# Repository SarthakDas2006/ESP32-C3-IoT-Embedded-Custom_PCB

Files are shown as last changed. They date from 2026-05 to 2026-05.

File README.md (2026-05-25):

# ESP32-C3-IoT-Embedded-Custom_PCB
4-layer ESP32-C3 based custom embedded IoT PCB featuring onboard temperature & humidity, light, and audio sensing, USB Type-C, Li-Po charging, and external flash memory. Designed for smart embedded systems, wireless IoT applications, portable sensing, automation, and edge device prototyping.
A professionally designed 4-layer ESP32-based IoT development board created using KiCad.
This project was developed to explore real-world PCB engineering concepts including multilayer routing, power management, USB-C integration, sensor interfacing, and signal integrity practices.

# 📸 Project Preview

## 3D PCB Render


# 🚀 Features

- ESP32-C3-WROOM module with onboard antenna
- 4-layer PCB stackup
- USB Type-C interface
- Li-Ion battery charging circuit
- Onboard voltage regulation
- SD card interface
- External SPI flash memory
- Temperature and humidity sensor interface
- Photo sensor interface
- Microphone and amplifier circuitry
- Reset and Boot buttons
- Ground plane optimization
- Decoupling and filtering capacitors
- Test points for debugging

# 🧠 PCB Stackup

| Layer | Function |
|---|---|
| Top Layer | Signal Routing |
| Inner Layer 1 | Ground Plane |
| Inner Layer 2 | Power Plane |
| Bottom Layer | Signal Routing |

The multilayer architecture was designed to improve:
- signal integrity
- grounding
- EMI performance
- power distribution

# 🛠️ Tools Used

- KiCad
- NextPCB DFM tool (HQDFM)
- SnapEDA
- ESP32-C3 Ecosystem
- Multiple datasheets

# 🔌 Hardware Blocks

## ESP32-C3 Module
Main microcontroller responsible for:
- WiFi/Bluetooth communication
- sensor interfacing
- data processing
- IoT applications

## USB Type-C Interface
Used for:
- power input
- USB communication
- firmware flashing

Includes:
- filtering capacitors
- protection circuitry
- proper VBUS routing

## Li-Ion Charging Circuit
Portable power management section featuring:
- battery charging
- regulated power delivery
- charging indication circuitry

## SD Card Interface
SPI-based SD card module used for:
- data logging
- external storage
- sensor data recording

## Sensor Interfaces
The PCB includes provisions for:
- temperature and humidity sensing
- ambient light sensing
- audio input through microphone amplifier circuitry

# 📂 Repository Structure

```text
ESP32-C3-IoT-Embedded-Custom-PCB/
│
├── BOM files/
├── Datasheets/
├── Drill files/
├── Gerber files/
├── Images/
├── custom 3d model libraries/
├── custom footprint libraries/
├── custom symbol libraries/
│
├── ESP32_IoT_4-layer_PCB.kicad_pcb
├── ESP32_IoT_4-layer_PCB.kicad_pro
├── ESP32_IoT_4-layer_PCB.kicad_sch
│
└── README.md
```

# 🎯 Project Objectives

This project was built to gain practical experience in:

- multilayer PCB design
- signal routing
- power integrity
- USB-C hardware implementation
- grounding techniques
- schematic hierarchy
- PCB manufacturing workflow

# 🧪 Key Design Considerations

- Ground plane continuity
- Proper decoupling capacitor placement
- Power filtering and stabilization
- Analog and digital section separation
- Pull-up and pull-down resistor implementation
- Modular schematic organization

# 📦 Manufacturing Ready

The project includes:
- PCB layout
- schematic
- Gerber files
- drill files
- BOM support

Compatible with manufacturers such as:
- JLCPCB
- PCBWay
- NextPCB

# 🔮 Future Improvements

- OTA firmware updates
- CAN bus support
- additional onboard sensors
- low-power optimization
- enclosure design
- impedance-controlled routing

# 📚 Learning Outcomes

Through this project, I developed understanding of:

- multilayer PCB stackups
- copper pours and ground planes
- signal routing
- ESP32 hardware integration
- USB-C implementation
- PCB manufacturing workflow
- hardware debugging concepts

# 👨‍💻 Author

**Sarthak Das**  
Electrical and Electronics Engineering Student at VIT Chennai

# ⭐ Support

If you like this project:
- Star the repository
- Fork the project
- Share feedback and suggestions

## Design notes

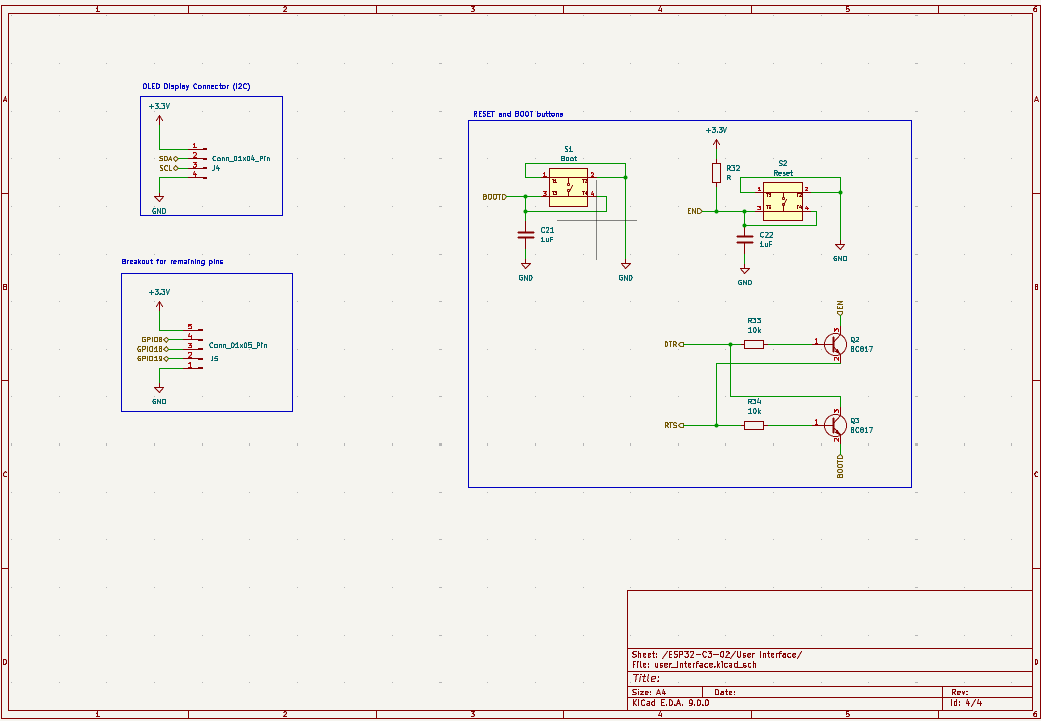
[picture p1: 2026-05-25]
Images/Schematic_editor_sheet_4.png

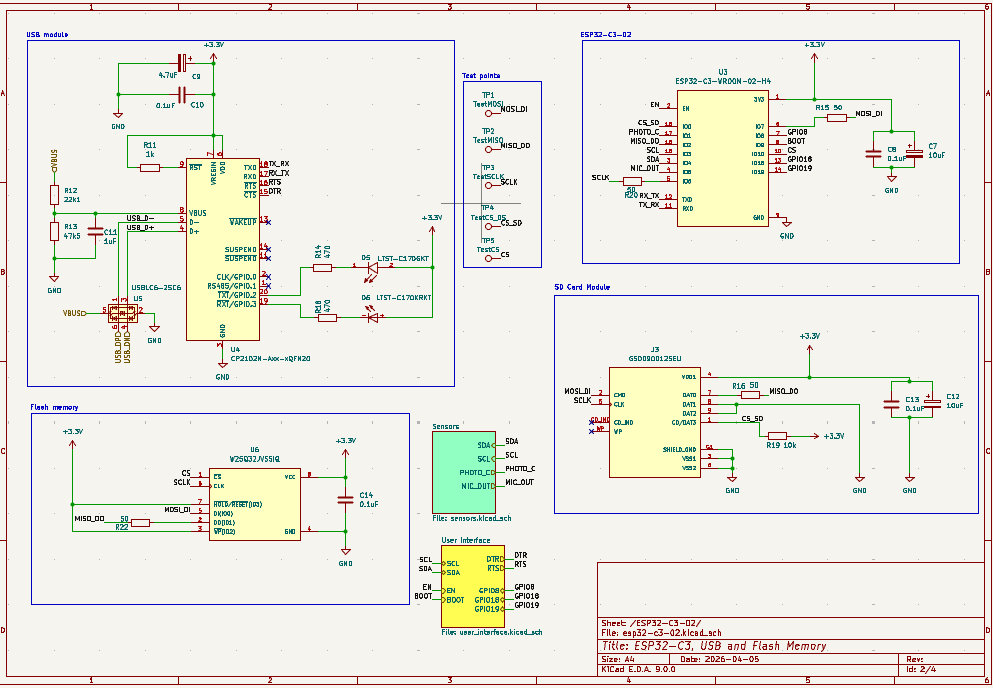
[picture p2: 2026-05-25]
Images/Schematic_editor_sheet_2.png

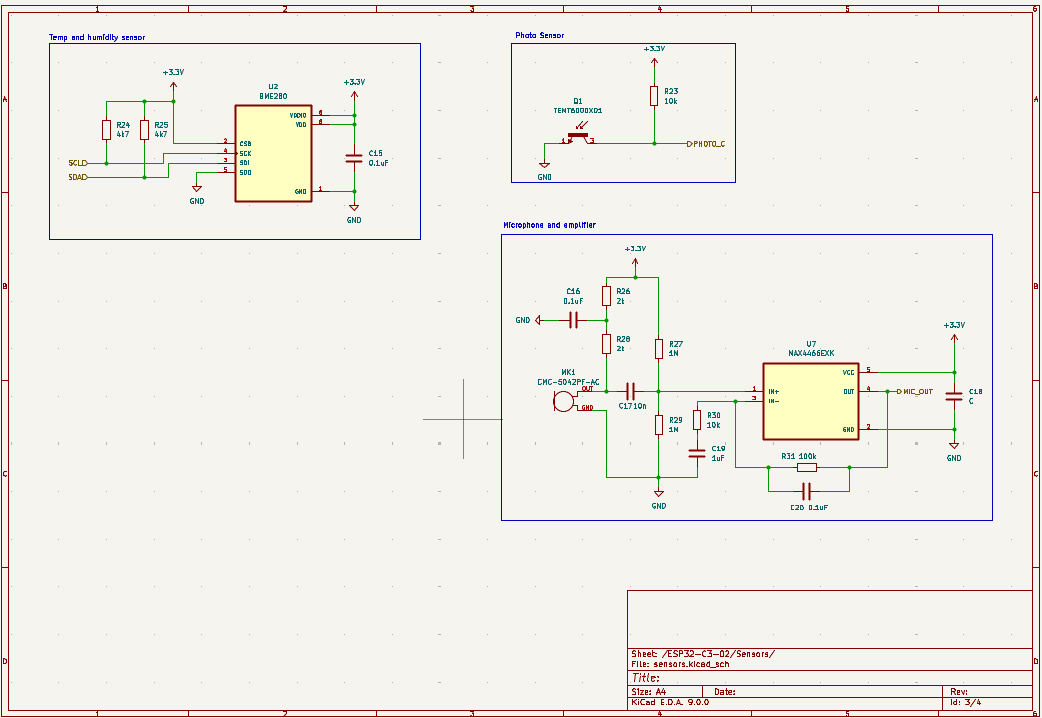
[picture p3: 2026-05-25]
Images/Schematic_editor_sheet_3.png

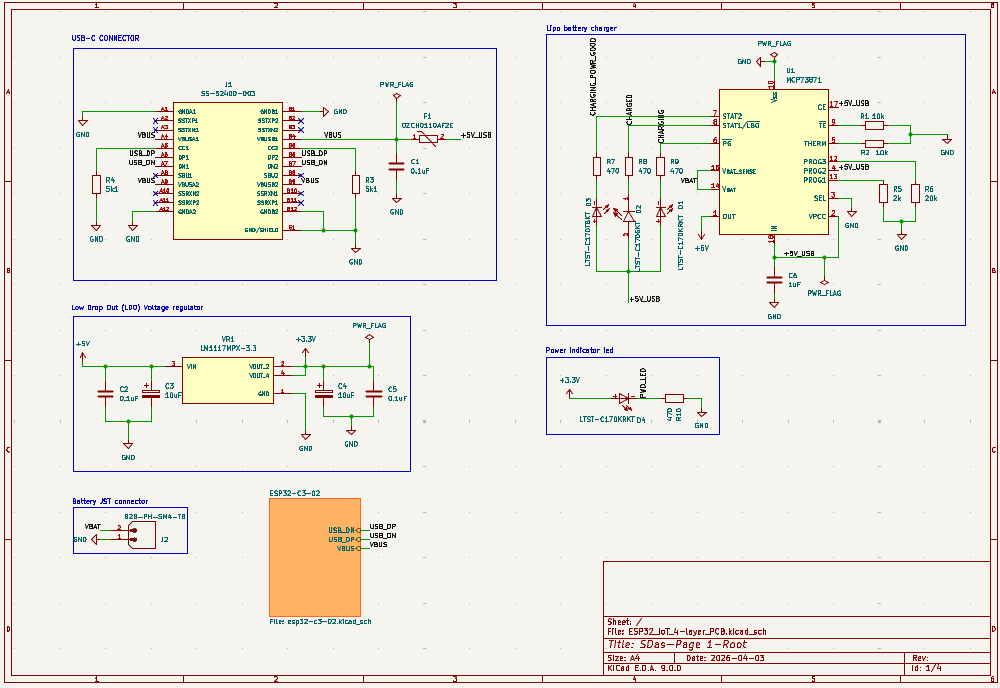
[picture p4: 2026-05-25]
Images/Schematic_editor_sheet_1.png

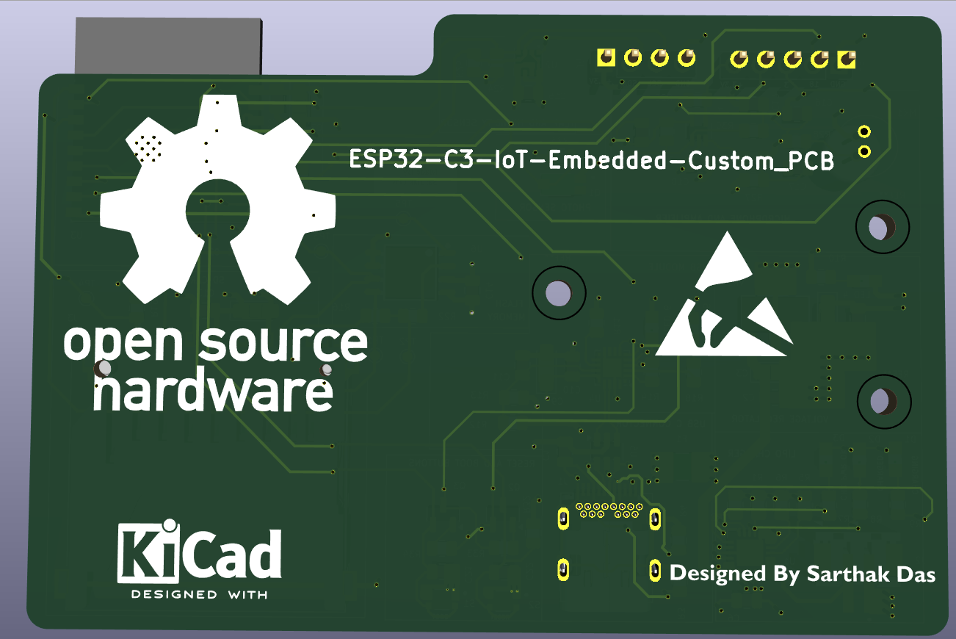
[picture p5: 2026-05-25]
Images/3d_model_bottom_view.png

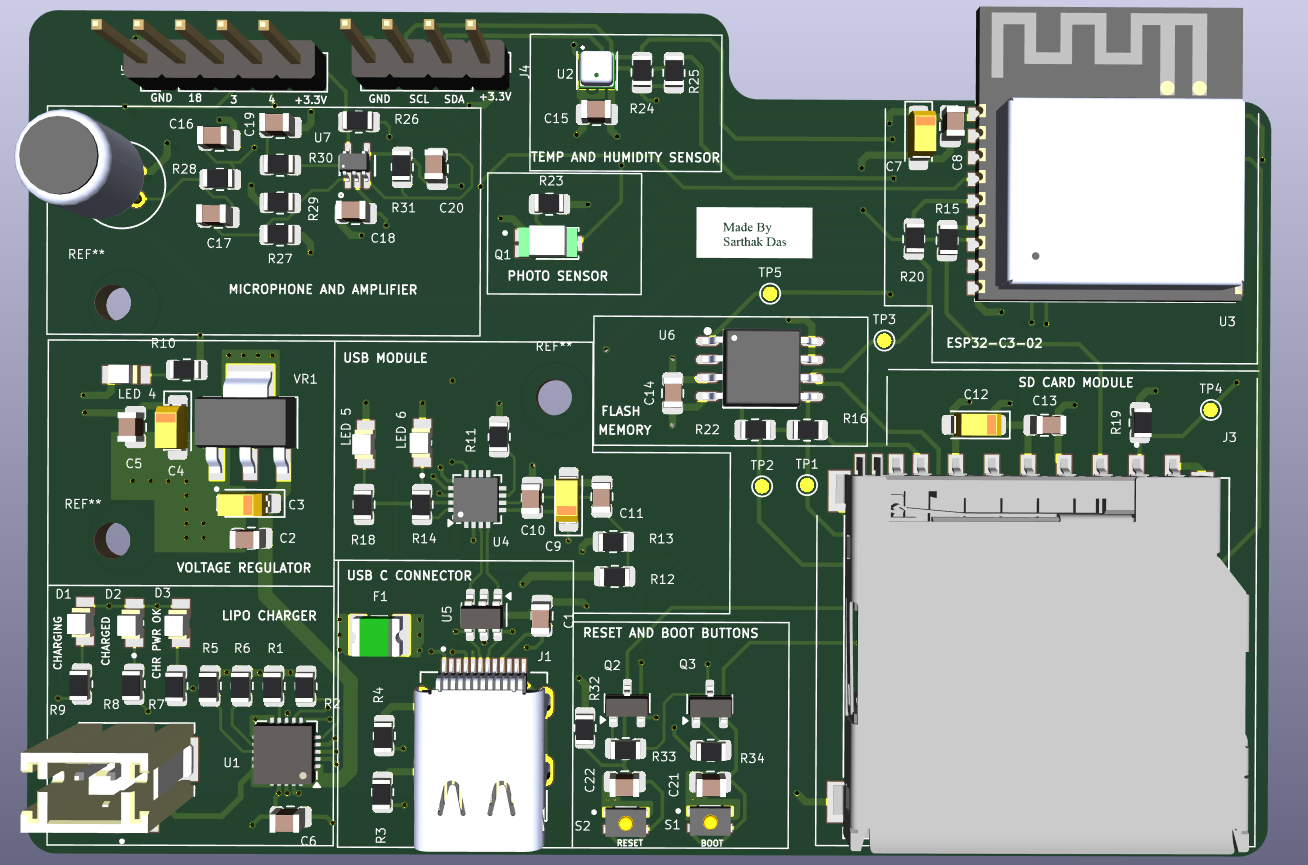
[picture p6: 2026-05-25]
Images/3d_model_top_view.png

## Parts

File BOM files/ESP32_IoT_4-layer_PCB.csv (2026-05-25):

Id | Designator | Footprint | Quantity | Designation | Supplier and ref
1 | R4,R3 | R_0805_2012Metric | 2 | 5k1
2 | R25,R24 | R_0805_2012Metric | 2 | 4k7
3 | R14,R18,R8,R10,R7,R9 | R_0805_2012Metric | 6 | 470
4 | C19,C11,C6,C22,C21 | C_0805_2012Metric | 5 | 1uF
5 | R29,R27 | R_0805_2012Metric | 2 | 1M
6 | MK1 | CUI_CMC-5042PF-AC | 1 | CMC-5042PF-AC
7 | J3 | AMPHENOL_GSD090012SEU | 1 | GSD090012SEU
8 | TP4 | TestPoint_Pad_D1.0mm | 1 | TestCS_DS
9 | D3 | DIOC200X125X110 | 1 | LTST-C170TBKT
10 | S2 | SW_USLPT2819DT2TR | 1 | Reset
11 | R26,R28,R5 | R_0805_2012Metric | 3 | 2k
12 | U2 | PSON65P250X250X100-8N | 1 | BME280
13 | U3 | MODULE_ESP32-C3-WROOM-02-H4 | 1 | ESP32-C3-WROOM-02-H4
14 | TP3 | TestPoint_Pad_D1.0mm | 1 | TestSCLK
15 | C1,C15,C5,C14,C16,C13,C2,C10,C8,C20 | C_0805_2012Metric | 10 | 0.1uF
16 | VR1 | VREG_LM1117MPX-3.3 | 1 | LM1117MPX-3.3
17 | U4 | SiliconLabs_QFN-20-1EP_3x3mm_P0.5mm_EP1.8x1.8mm | 1 | CP2102N-Axx-xQFN20
18 | Q2,Q3 | SOT-23 | 2 | BC817
19 | R11 | R_0805_2012Metric | 1 | 1k
20 | R32 | R_0805_2012Metric | 1 | R
21 | U1 | QFN-20-1EP_4x4mm_P0.5mm_EP2.5x2.5mm | 1 | MCP73871
22 | R15,R22,R16,R20 | R_0805_2012Metric | 4 | 50
23 | R19,R1,R2,R30,R34,R33,R23 | R_0805_2012Metric | 7 | 10k
24 | C4,C7,C3,C12 | CP_EIA-3216-18_Kemet-A_Pad1.58x1.35mm_HandSolder | 4 | 10uF
25 | LED 5,LED 4,D1 | DIOC200X125X110R | 3 | LTST-C170KRKT
26 | R31 | R_0805_2012Metric | 1 | 100k
27 | C9 | CP_EIA-3216-18_Kemet-A_Pad1.58x1.35mm_HandSolder | 1 | 4.7uF
28 | J2 | JST_B2B-PH-SM4-TB | 1 | B2B-PH-SM4-TB
29 | J5 | PinHeader_1x05_P2.54mm_Vertical | 1 | Conn_01x05_Pin
30 | J1 | BELFUSE_SS-52400-003 | 1 | SS-52400-003
31 | F1 | FUSC3225X100N | 1 | 0ZCH0110AF2E
32 | R12 | R_0805_2012Metric | 1 | 22k1
33 | U6 | SOIC127P790X216-8N | 1 | W25Q32JVSSIQ
34 | TP5 | TestPoint_Pad_D1.0mm | 1 | TestCS
35 | LED 6,D2 | LED_LTST-C170GKT | 2 | LTST-C170GKT
36 | U5 | SOT-23-6 | 1 | USBLC6-2SC6
37 | C17 | C_0805_2012Metric | 1 | 10n
38 | U7 | SOT65P210X110-5N | 1 | MAX4466EXK
39 | J4 | PinHeader_1x04_P2.54mm_Vertical | 1 | Conn_01x04_Pin
40 | C18 | C_0805_2012Metric | 1 | C
41 | S1 | SW_USLPT2819DT2TR | 1 | Boot
42 | TP1 | TestPoint_Pad_D1.0mm | 1 | TestMOSI
43 | R13 | R_0805_2012Metric | 1 | 47k5
44 | R6 | R_0805_2012Metric | 1 | 20k
45 | Q1 | TRANS_TEMT6000X01 | 1 | TEMT6000X01
46 | TP2 | TestPoint_Pad_D1.0mm | 1 | TestMISO

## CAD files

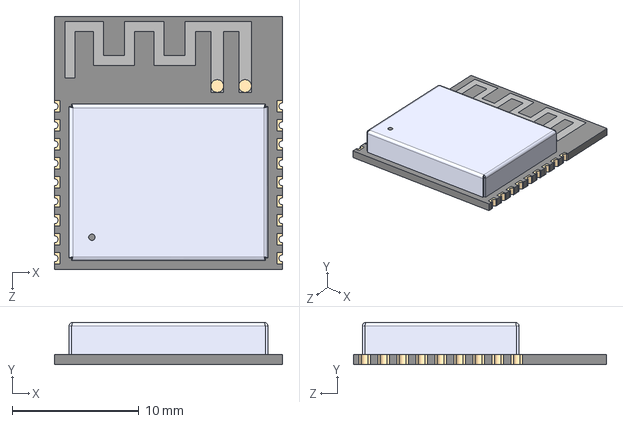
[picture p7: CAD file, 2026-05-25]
custom 3d model libraries/ESP32-C3-WROOM-02-H4.step
18.0 x 3.35 x 20.0 mm

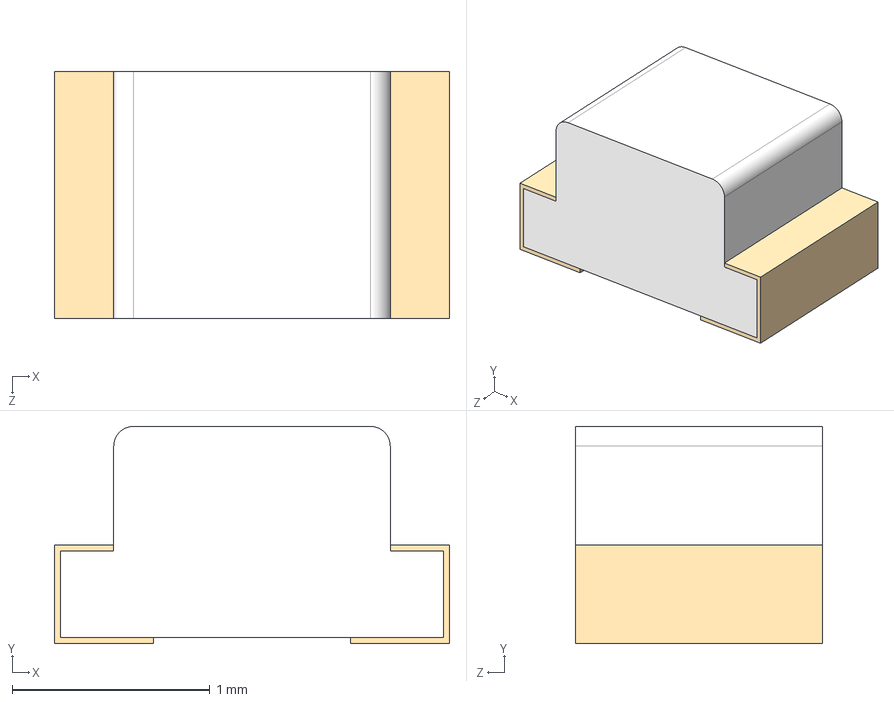
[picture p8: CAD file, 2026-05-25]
custom 3d model libraries/LTST-C170TBKT.step
2.00 x 1.10 x 1.25 mm

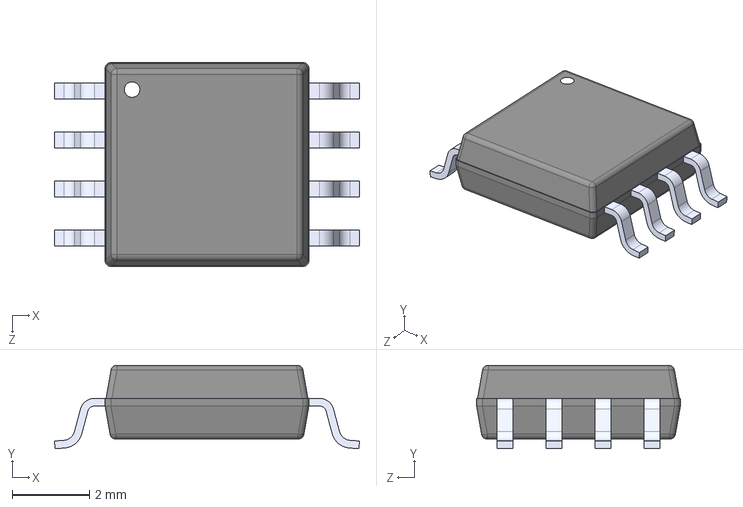
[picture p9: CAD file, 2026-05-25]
custom 3d model libraries/W25Q32JVSSIQ.step
7.90 x 2.16 x 5.28 mm

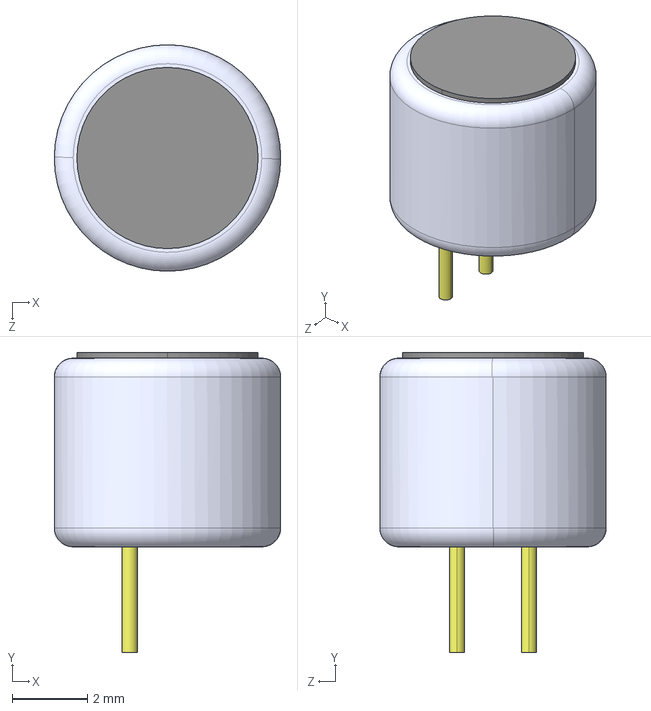
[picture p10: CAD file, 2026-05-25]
custom 3d model libraries/CMC-5042PF-AC.step
6.00 x 7.95 x 6.00 mm

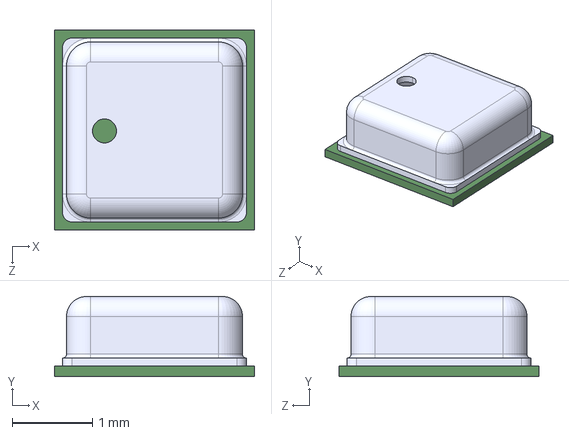
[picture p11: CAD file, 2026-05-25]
custom 3d model libraries/BME280.step
2.50 x 1.00 x 2.50 mm

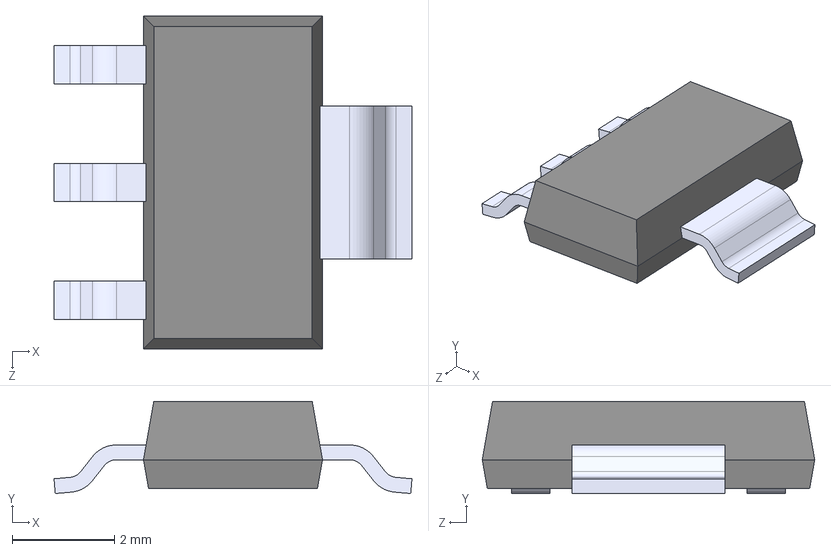
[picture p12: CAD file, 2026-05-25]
custom 3d model libraries/LM1117MPX-3.3.step
7.00 x 1.80 x 6.50 mm

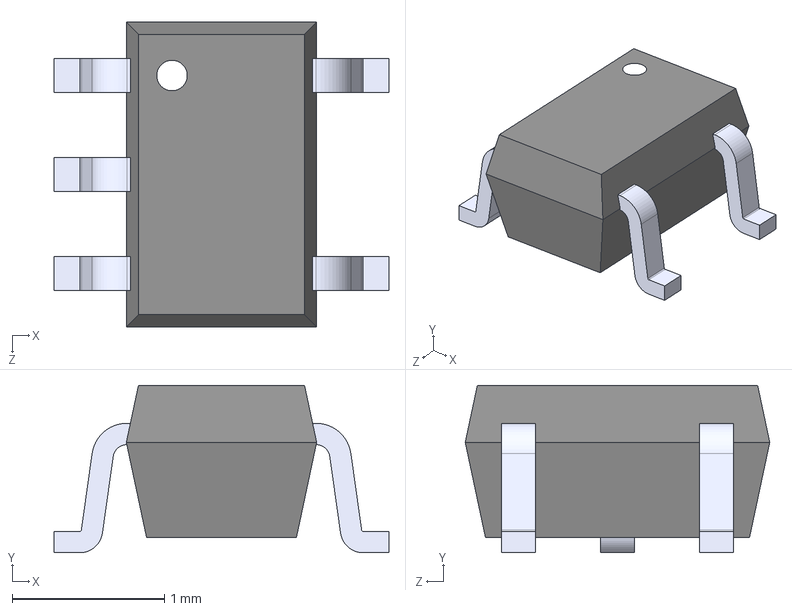
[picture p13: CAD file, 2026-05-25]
custom 3d model libraries/MAX4466EXK.step
2.20 x 1.10 x 2.00 mm

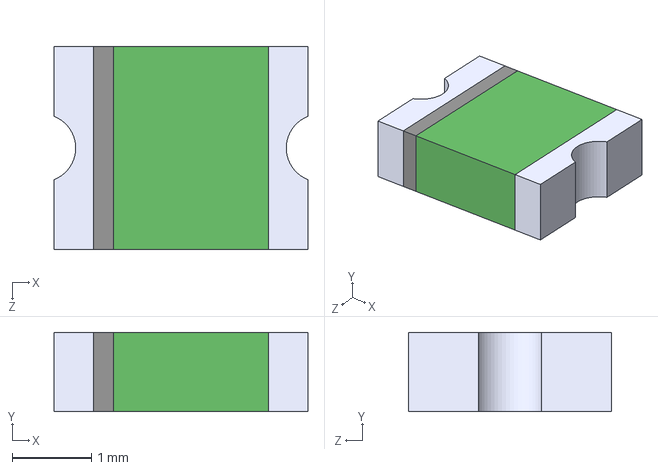
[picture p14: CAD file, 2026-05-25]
custom 3d model libraries/0ZCH0110AF2E.step
3.21 x 1.00 x 2.58 mm

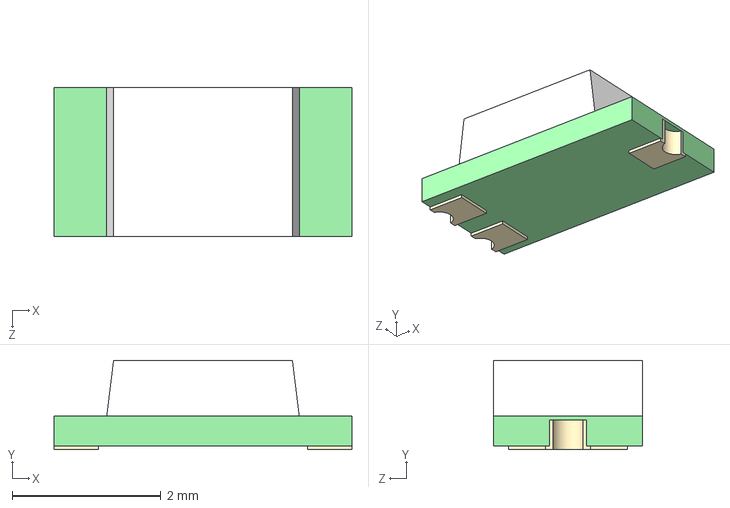
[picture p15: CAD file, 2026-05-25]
custom 3d model libraries/TEMT6000X01.step
4.00 x 1.20 x 2.00 mm

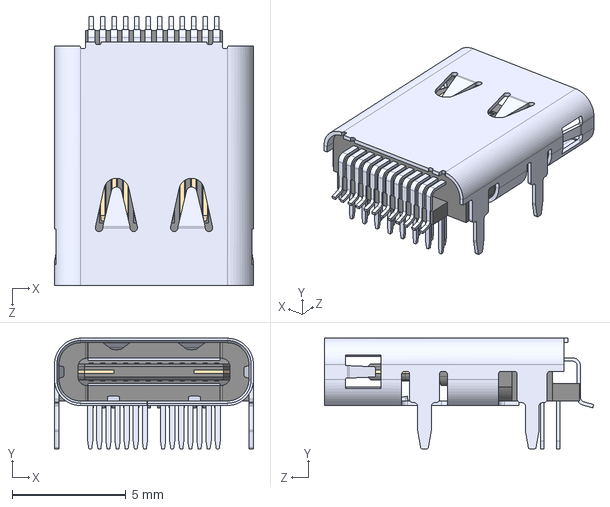
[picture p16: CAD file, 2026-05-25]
custom 3d model libraries/SS-52400-003.step
8.74 x 4.86 x 11.8 mm

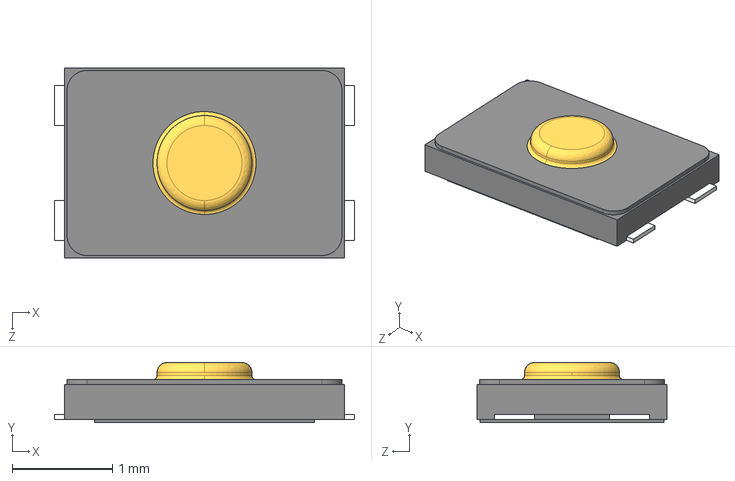
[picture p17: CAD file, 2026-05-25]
custom 3d model libraries/USLPT2819DT2TR.step
3.00 x 0.6 x 1.90 mm

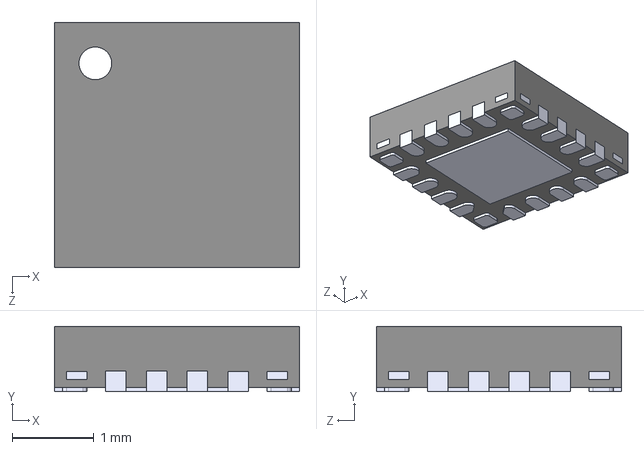
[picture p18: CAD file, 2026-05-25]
custom 3d model libraries/CP2102N-A02-GQFN20--3DModel-STEP-269445.STEP
3.00 x 0.8 x 3.00 mm

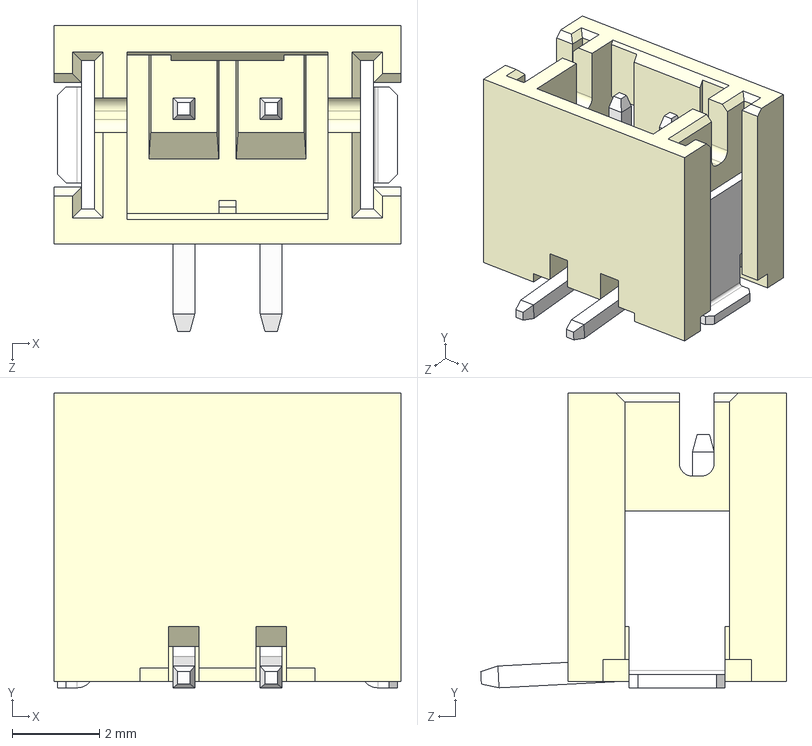
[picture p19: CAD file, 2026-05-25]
custom 3d model libraries/B2B-PH-SM4-TB.step
7.95 x 6.75 x 7.00 mm

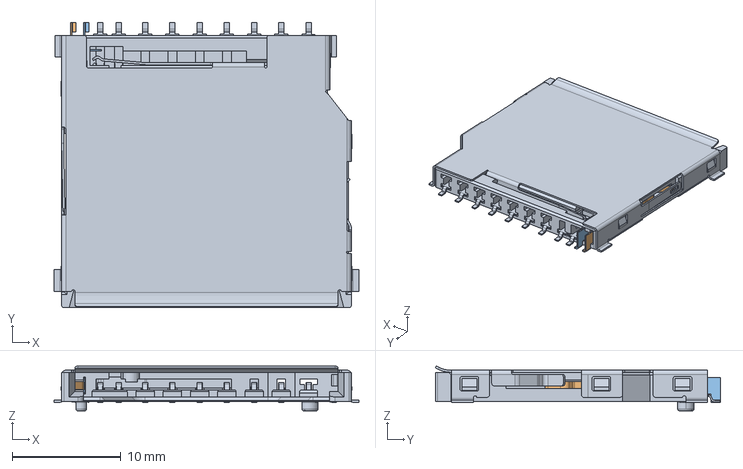
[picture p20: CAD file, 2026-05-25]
custom 3d model libraries/GSD090012SEU.step
28.0 x 26.2 x 4.13 mm

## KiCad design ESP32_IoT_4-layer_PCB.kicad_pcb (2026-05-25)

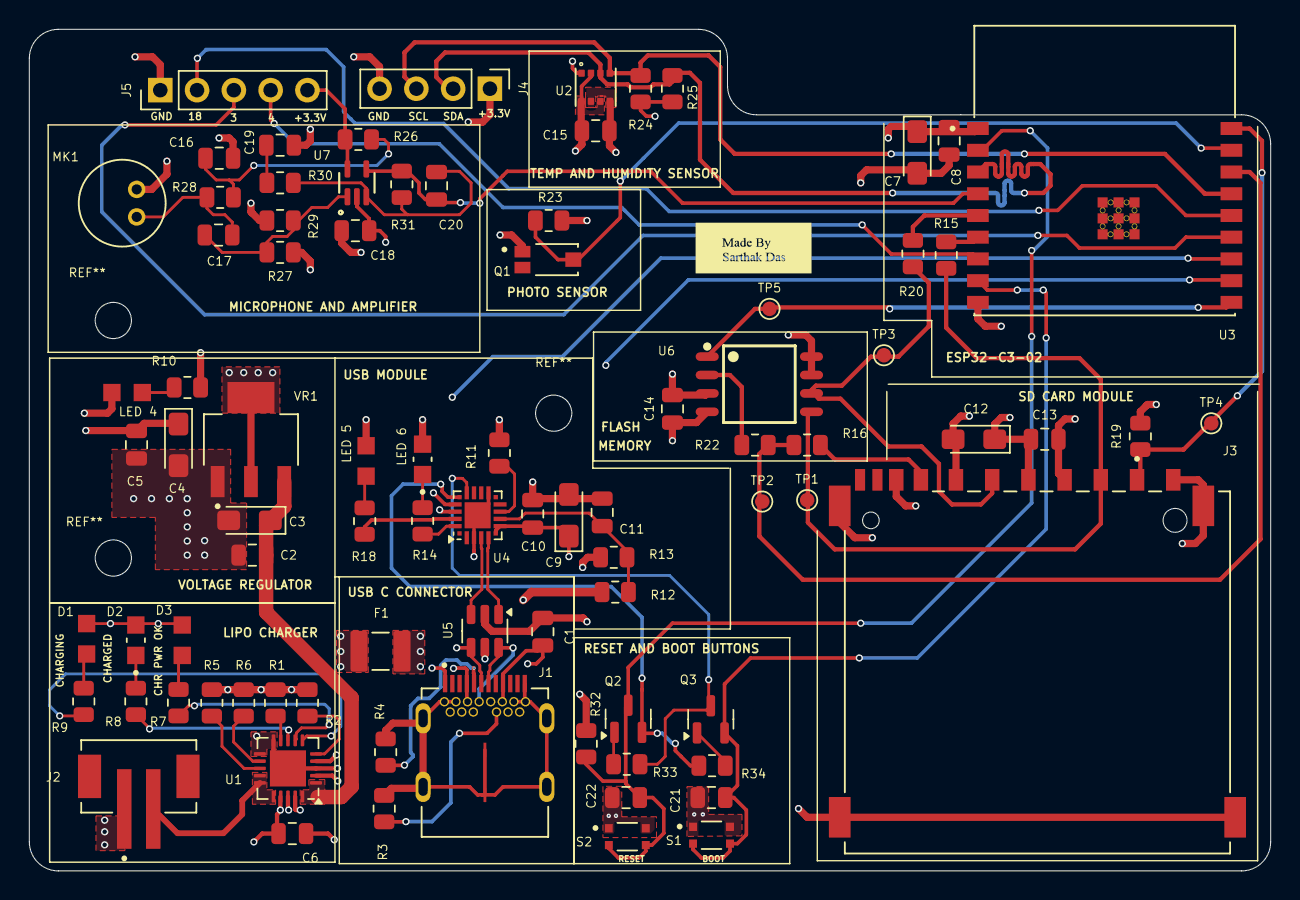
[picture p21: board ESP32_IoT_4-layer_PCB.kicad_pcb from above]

Board: 4 copper layers, 85.7 x 58.1 mm, 85 parts (0 on the bottom side), 57 nets.

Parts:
C1, C2, C5, C8, C10, C13, C14, C15, C16, C20: 0.1uF; C_0805_2012Metric
C3, C4, C7, C12: 10uF; CP_EIA-3216-18_Kemet-A_Pad1.58x1.35mm_HandSolder
C6, C11, C19, C21, C22: 1uF; C_0805_2012Metric
C9: 4.7uF; CP_EIA-3216-18_Kemet-A_Pad1.58x1.35mm_HandSolder
C17: 10n; C_0805_2012Metric
C18: C; C_0805_2012Metric
D1: LTST-C170KRKT; DIOC200X125X110R
D2: LTST-C170GKT; LED_LTST-C170GKT
D3: LTST-C170TBKT; DIOC200X125X110
F1: 0ZCH0110AF2E; FUSC3225X100N
J1: SS-52400-003; BELFUSE_SS-52400-003
J2: B2B-PH-SM4-TB; JST_B2B-PH-SM4-TB
J3: GSD090012SEU; AMPHENOL_GSD090012SEU
J4: Conn_01x04_Pin; PinHeader_1x04_P2.54mm_Vertical
J5: Conn_01x05_Pin; PinHeader_1x05_P2.54mm_Vertical
LED 4, LED 5: LTST-C170KRKT; DIOC200X125X110R
LED 6: LTST-C170GKT; LED_LTST-C170GKT
MK1: CMC-5042PF-AC; CUI_CMC-5042PF-AC
Q1: TEMT6000X01; TRANS_TEMT6000X01
Q2, Q3: BC817; SOT-23
R1, R2, R19, R23, R30, R33, R34: 10k; R_0805_2012Metric
R3, R4: 5k1; R_0805_2012Metric
R5, R26, R28: 2k; R_0805_2012Metric
R6: 20k; R_0805_2012Metric
R7, R8, R9, R10, R14, R18: 470; R_0805_2012Metric
R11: 1k; R_0805_2012Metric
R12: 22k1; R_0805_2012Metric
R13: 47k5; R_0805_2012Metric
R15, R16, R20, R22: 50; R_0805_2012Metric
R24, R25: 4k7; R_0805_2012Metric
R27, R29: 1M; R_0805_2012Metric
R31: 100k; R_0805_2012Metric
R32: R; R_0805_2012Metric
S1: Boot; SW_USLPT2819DT2TR
S2: Reset; SW_USLPT2819DT2TR
TP1: TestMOSI; TestPoint_Pad_D1.0mm
TP2: TestMISO; TestPoint_Pad_D1.0mm
TP3: TestSCLK; TestPoint_Pad_D1.0mm
TP4: TestCS_DS; TestPoint_Pad_D1.0mm
TP5: TestCS; TestPoint_Pad_D1.0mm
U1: MCP73871; QFN-20-1EP_4x4mm_P0.5mm_EP2.5x2.5mm
U2: BME280; PSON65P250X250X100-8N
U3: ESP32-C3-WROOM-02-H4; MODULE_ESP32-C3-WROOM-02-H4
U4: CP2102N-Axx-xQFN20; SiliconLabs_QFN-20-1EP_3x3mm_P0.5mm_EP1.8x1.8mm
U5: USBLC6-2SC6; SOT-23-6
U6: W25Q32JVSSIQ; SOIC127P790X216-8N
U7: MAX4466EXK; SOT65P210X110-5N
VR1: LM1117MPX-3.3; VREG_LM1117MPX-3.3

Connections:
+3.3V: C4.1, C5.1, C7.1, C8.1, C9.1, C10.2, C12.1, C13.1, C14.1, C15.1, C18.1, J3.4 (VDD1), J4.1, J5.5, LED 4.+, LED 5.+, LED 6.2, R11.1, R19.2, R23.1, R24.1, R25.1, R26.1, R27.1, R32.1, U2.2 (CSB), U2.6 (VDDIO), U2.8 (VDD), U3.1 (3V3), U4.6 (VDD), U4.7 (VREGIN), U6.3 (~WP(IO2)), U6.7 (~HOLD/~RESET(IO3)), U6.8 (VCC), U7.5 (VCC), VR1.2 (VOUT_2), VR1.4 (VOUT_4)
+5V: C2.1, C3.1, U1.1 (OUT), U1.20 (OUT), VR1.3 (VIN)
/+5V_USB: C6.1, D1.+, D2.2, D3.+, F1.2, U1.2 (VPCC), U1.4 (PROG2), U1.17 (CE), U1.18 (IN), U1.19 (IN)
/CHARGED: R8.1, U1.8 (STAT1/~LBO)
/CHARGING: R9.1, U1.6 (~PG)
/CHARGING_POWR_GOOD: R7.1, U1.7 (STAT2)
/ESP32-C3-02/BOOT: C21.1, Q3.2 (E), S1.3, S1.4, U3.8 (IO9)
/ESP32-C3-02/CS: TP5.1, U3.10 (IO10), U6.1 (~CS)
/ESP32-C3-02/CS_SD: J3.1 (CD/DAT3), R19.1, TP4.1, U3.18 (IO0)
/ESP32-C3-02/DTR: Q3.3 (C), R33.1, U4.15 (~CTS)
/ESP32-C3-02/EN: C22.1, Q2.3 (C), R32.2, S2.3, S2.4, U3.2 (EN)
/ESP32-C3-02/GPIO8: J5.4, U3.7 (IO8)
/ESP32-C3-02/GPIO18: J5.3, U3.13 (IO18)
/ESP32-C3-02/GPIO19: J5.2, U3.14 (IO19)
/ESP32-C3-02/MIC_OUT: C20.2, R31.1, U3.4 (IO5), U7.4 (OUT)
/ESP32-C3-02/MISO_DO: R16.2, R22.1, TP2.1, U3.16 (IO2)
/ESP32-C3-02/MOSI_DI: J3.2 (CMD), R15.2, TP1.1, U6.5 (DI(IO0))
/ESP32-C3-02/PHOTO_C: Q1.3, R23.2, U3.17 (IO1)
/ESP32-C3-02/RTS: Q2.2 (E), R34.1, U4.16 (~RTS)
/ESP32-C3-02/RX_TX: U3.12 (TXD), U4.17 (RXD)
/ESP32-C3-02/SCL: J4.3, R24.2, U2.4 (SCK), U3.15 (IO3)
/ESP32-C3-02/SCLK: J3.5 (CLK), R20.1, TP3.1, U6.6 (CLK)
/ESP32-C3-02/SDA: J4.2, R25.2, U2.3 (SDI), U3.3 (IO4)
/ESP32-C3-02/TX_RX: U3.11 (RXD), U4.18 (TXD)
/ESP32-C3-02/USB_D+: U4.4 (D+), U5.3 (I/O2)
/ESP32-C3-02/USB_D-: U4.5 (D-), U5.1 (I/O1)
/PWD_LED: LED 4.-, R10.2
/USB_DN: J1.A7 (DN1), J1.B7 (DN2), U5.6 (I/O1)
/VBAT: J2.2, U1.14 (V_{BAT}), U1.15 (V_{BAT}), U1.16 (V_{BAT_SENSE})
/VBUS: C1.1, F1.1, J1.A4 (VBUSA1), J1.A9 (VBUSA2), J1.B4 (VBUSB1), J1.B9 (VBUSB2), R12.1, U5.5 (VBUS)
GND: C1.2, C2.2, C3.2, C4.2, C5.2, C6.2, C7.2, C8.2, C9.2, C10.1, C11.2, C12.2, C13.2, C14.2, C15.2, C16.1, C18.2, C19.2, C21.2, C22.2, J1.A1 (GNDA1), J1.A12 (GNDA2), J1.B1 (GNDB1), J1.B12 (GNDB2), J1.G1 (GND/SHIELD), J1.G2 (GND/SHIELD), J1.G3 (GND/SHIELD), J1.G4 (GND/SHIELD), J1.S1 (GND/SHIELD), J1.S2 (GND/SHIELD), J1.S3 (GND/SHIELD), J1.S4 (GND/SHIELD), J2.1, J3.3 (VSS1), J3.6 (VSS2), J3.8 (DAT1), J3.9 (DAT2), J3.G1 (SHIELD_GND), J3.G2 (SHIELD_GND), J3.G3 (SHIELD_GND), J3.G4 (SHIELD_GND), J4.4, J5.1, MK1.GND, Q1.1, R1.2, R2.2, R3.2, R4.2, R5.2, R6.2, R10.1, R13.2, R29.2, S1.1, S1.2, S2.1, S2.2, U1.3 (SEL), U1.10 (V_{SS}), U1.11 (V_{SS}), U1.21 (V_{SS}), U2.1 (GND), U2.5 (SDO), U2.7 (GND), U3.9 (GND), U3.19 (GND), U3.20 (GND), U3.21 (GND), U3.22 (GND), U3.23 (GND), U3.24 (GND), U3.25 (GND), U3.26 (GND), U3.27 (GND), U3.28 (GND), U3.29 (GND), U3.30 (GND), U3.31 (GND), U3.32 (GND), U3.33 (GND), U3.34 (GND), U3.35 (GND), U3.36 (GND), U3.37 (GND), U3.38 (GND), U3.39 (GND), U4.3 (GND), U4.12 (GND), U4.21 (GND), U5.2 (GND), U6.4 (GND), U7.2 (GND), VR1.1 (GND)
unnamed: C16.2, R26.2, R28.1
unnamed: C17.1, MK1.OUT, R28.2
unnamed: C19.1, R30.2
unnamed: D1.-, R9.2
unnamed: D2.1, R8.2
unnamed: D3.-, R7.2
unnamed: LED 6.1, R14.2
unnamed: LED 5.-, R18.2
unnamed: J1.A5 (CC1), J1.A6 (DP1), J1.B6 (DP2), R4.1, U5.4 (I/O2)
unnamed: J1.B5 (CC2), R3.1
unnamed: J3.7 (DAT0), R16.1
unnamed: Q2.1 (B), R33.2
unnamed: Q3.1 (B), R34.2
unnamed: R5.1, U1.13 (PROG1)
unnamed: R6.1, U1.12 (PROG3)
unnamed: R2.1, U1.5 (THERM)
unnamed: R1.1, U1.9 (~TE)
unnamed: R20.2, U3.5 (IO6)
unnamed: R15.1, U3.6 (IO7)
unnamed: C11.1, R12.2, R13.1, U4.8 (VBUS)
unnamed: R11.2, U4.9 (~RST)
unnamed: R18.1, U4.19 (~RXT/GPIO.3)
unnamed: R14.1, U4.20 (~TXT/GPIO.2)
unnamed: R22.2, U6.2 (DO(IO1))
unnamed: C17.2, R27.2, R29.1, U7.1 (IN+)
unnamed: C20.1, R30.1, R31.2, U7.3 (IN-)
